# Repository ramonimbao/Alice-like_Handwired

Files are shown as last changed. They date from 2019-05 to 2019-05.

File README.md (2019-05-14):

# "fAuxLICE"

An 3D printable Alice-like mechanical keyboard

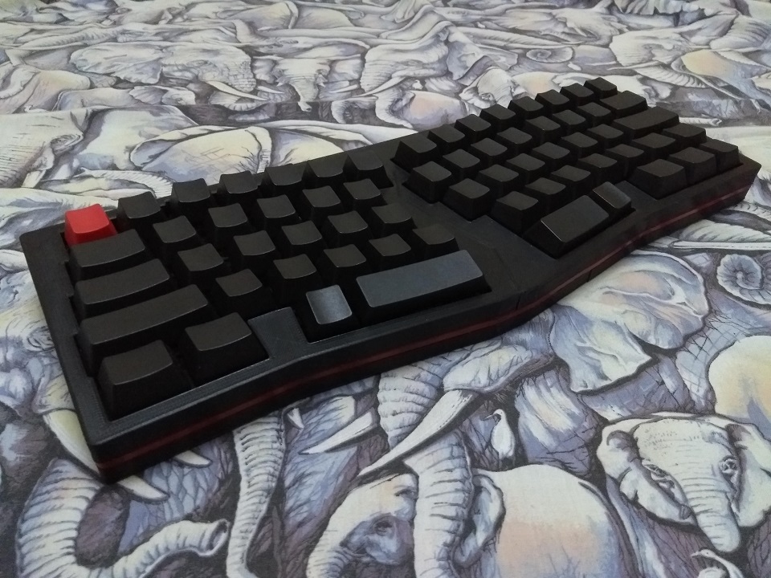
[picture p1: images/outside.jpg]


## Layout

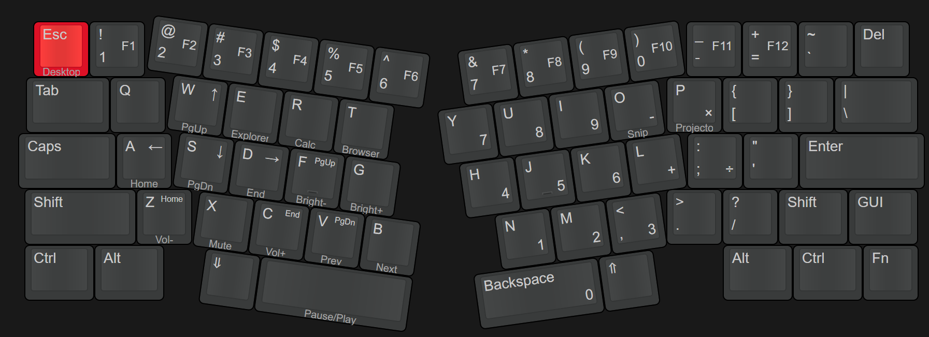
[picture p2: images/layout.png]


[Keyboard Layout Editor](http://www.keyboard-layout-editor.com/#/gists/7f17a55de07d88c1f975089b07f053b1)

## Components

### Required components

- 64× switches of your choice
- 4× plate-mounted Costar stabilizers
- 108-key keycap set
- 64× diodes
- Wires
- 14× M3×16 countersunk screws
- 2× M3×12 countersunk screws

### Optional components

- 1× M3×8 countersunk screw
- 1× M3×10 countersunk screw
- 1× M3×12 countersunk screw
- 1× M3×16 countersunk screw
- 1× M3×20 countersunk screw

The optional components are for reinforcing the top halves. They're not required. A proper glue up would be probably enough for the two halves.

## Wiring diagram

The keyboard is wired in a 5-row, 14-column configuration. Sorry for starting my row/column index at 1!

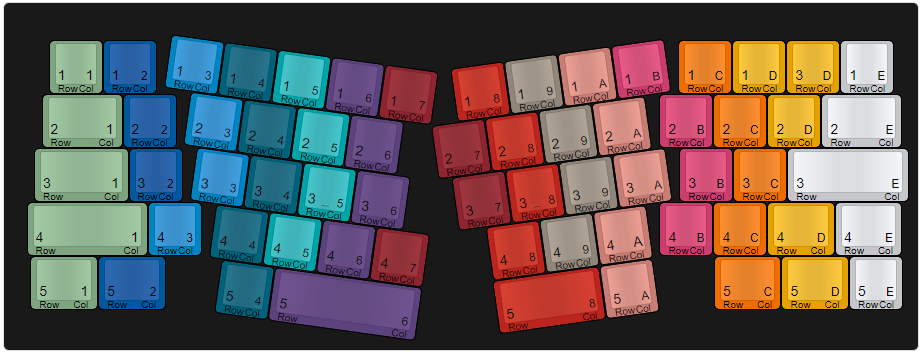
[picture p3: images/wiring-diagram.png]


## Build notes

The accent pieces have an extra 5mm sticking out. You should be able to cut them to the perfect length, and make the transitions between the two seamless. Glue the accent pieces to the bottom halves.

The halves do not lock into each other. I used a combination of glue and diode trimmings melted into the plastic.

I used a knife tip on my soldering iron and set the temperature to 250°C. Place the diode lead trimming on the plastic and melt it. I did this only on the inside surfaces so it wouldn't matter if it's ugly. I then supplemented it by melting loose filament into place.

## Firmware

The firmware included is for the STM32F103 ["Blue Pill"](https://wiki.stm32duino.com/index.php?title=Blue_Pill) board.

The STM32duino bootloader is not necessary. Simply flash the board using an ST-Link programmer.

## More info

More info can be found in [this blog post](https://ramonimbao.github.io/alice-like-keyboard/).

## License

This project is licensed under the MIT license. See the `LICENSE.md` for more details.

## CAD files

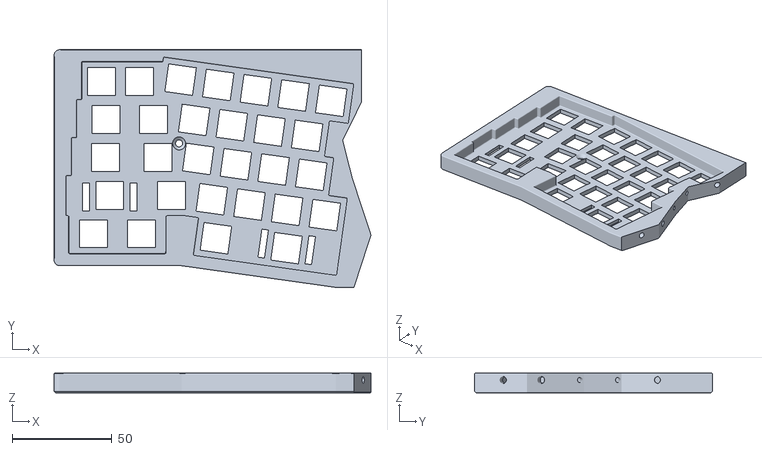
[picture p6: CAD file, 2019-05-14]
STL/fAuxLICE_Top_Left.stl
158.8 x 119.1 x 10.0

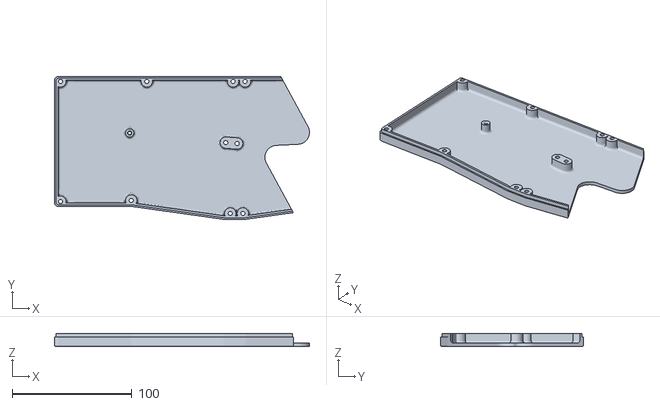
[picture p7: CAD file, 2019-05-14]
STL/fAuxLICE_Bottom_Left.stl
212.7 x 119.1 x 11.0

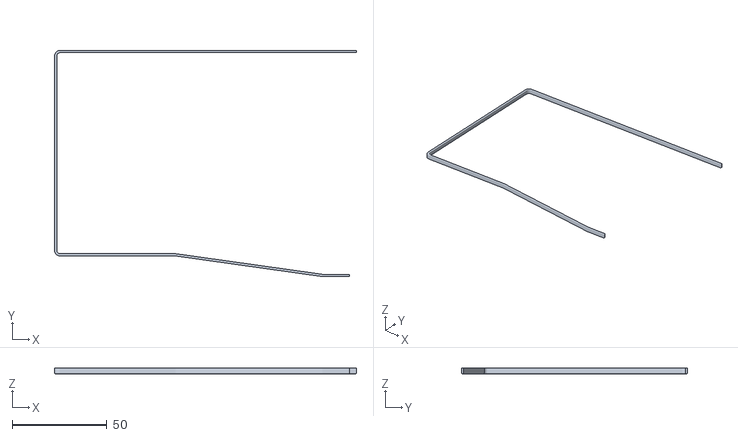
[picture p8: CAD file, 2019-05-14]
STL/fAuxLICE_Accent_Left.stl
159.0 x 119.1 x 3.00

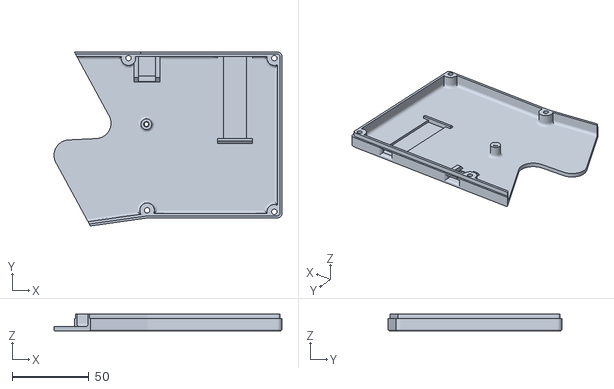
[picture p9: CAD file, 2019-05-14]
STL/fAuxLICE_Bottom_Right.stl
148.7 x 113.5 x 11.0

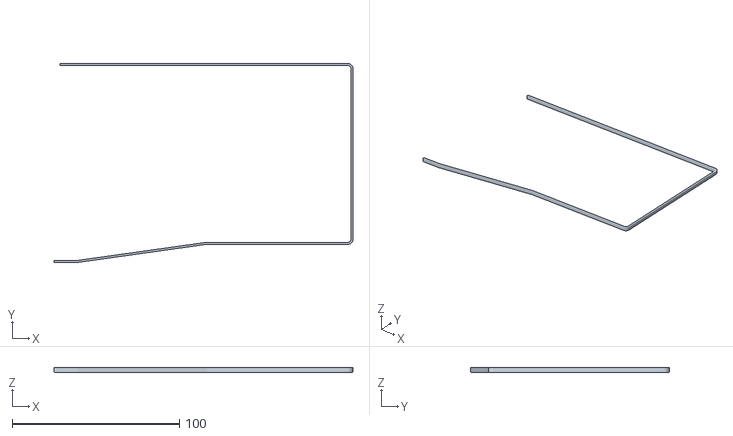
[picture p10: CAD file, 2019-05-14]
STL/fAuxLICE_Accent_Right.stl
179.0 x 119.1 x 3.00

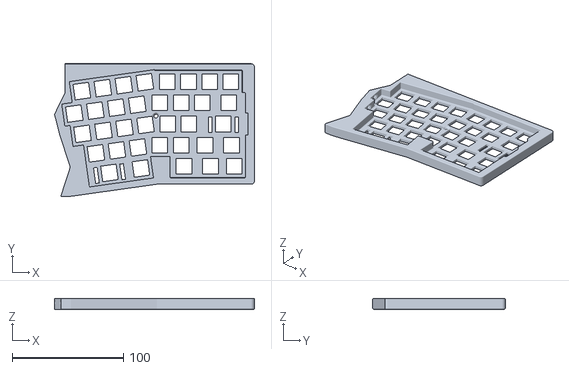
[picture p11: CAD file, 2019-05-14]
STL/fAuxLICE_Top_Right.stl
179.7 x 119.1 x 10.0

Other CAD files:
fusion360/fAuxLICE.f3d

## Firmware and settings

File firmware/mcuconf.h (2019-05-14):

/*
    ChibiOS - Copyright (C) 2006..2015 Giovanni Di Sirio

    Licensed under the Apache License, Version 2.0 (the "License");
    you may not use this file except in compliance with the License.
    You may obtain a copy of the License at

        http://www.apache.org/licenses/LICENSE-2.0

    Unless required by applicable law or agreed to in writing, software
    distributed under the License is distributed on an "AS IS" BASIS,
    WITHOUT WARRANTIES OR CONDITIONS OF ANY KIND, either express or implied.
    See the License for the specific language governing permissions and
    limitations under the License.
*/

#ifndef _MCUCONF_H_
#define _MCUCONF_H_

#define STM32F103_MCUCONF

/*
 * STM32F103 drivers configuration.
 * The following settings override the default settings present in
 * the various device driver implementation headers.
 * Note that the settings for each driver only have effect if the whole
 * driver is enabled in halconf.h.
 *
 * IRQ priorities:
 * 15...0       Lowest...Highest.
 *
 * DMA priorities:
 * 0...3        Lowest...Highest.
 */

/*
 * HAL driver system settings.
 */
#define STM32_NO_INIT                       FALSE
#define STM32_HSI_ENABLED                   TRUE
#define STM32_LSI_ENABLED                   FALSE
#define STM32_HSE_ENABLED                   TRUE
#define STM32_LSE_ENABLED                   FALSE
#define STM32_SW                            STM32_SW_PLL
#define STM32_PLLSRC                        STM32_PLLSRC_HSE
#define STM32_PLLXTPRE                      STM32_PLLXTPRE_DIV1
#define STM32_PLLMUL_VALUE                  9
#define STM32_HPRE                          STM32_HPRE_DIV1
#define STM32_PPRE1                         STM32_PPRE1_DIV2
#define STM32_PPRE2                         STM32_PPRE2_DIV2
#define STM32_ADCPRE                        STM32_ADCPRE_DIV4
#define STM32_USB_CLOCK_REQUIRED            TRUE
#define STM32_USBPRE                        STM32_USBPRE_DIV1P5
#define STM32_MCOSEL                        STM32_MCOSEL_NOCLOCK
#define STM32_RTCSEL                        STM32_RTCSEL_HSEDIV
#define STM32_PVD_ENABLE                    FALSE
#define STM32_PLS                           STM32_PLS_LEV0

/*
 * ADC driver system settings.
 */
#define STM32_ADC_USE_ADC1                  FALSE
#define STM32_ADC_ADC1_DMA_PRIORITY         2
#define STM32_ADC_ADC1_IRQ_PRIORITY         6

/*
 * CAN driver system settings.
 */
#define STM32_CAN_USE_CAN1                  FALSE
#define STM32_CAN_CAN1_IRQ_PRIORITY         11

/*
 * EXT driver system settings.
 */
#define STM32_EXT_EXTI0_IRQ_PRIORITY        6
#define STM32_EXT_EXTI1_IRQ_PRIORITY        6
#define STM32_EXT_EXTI2_IRQ_PRIORITY        6
#define STM32_EXT_EXTI3_IRQ_PRIORITY        6
#define STM32_EXT_EXTI4_IRQ_PRIORITY        6
#define STM32_EXT_EXTI5_9_IRQ_PRIORITY      6
#define STM32_EXT_EXTI10_15_IRQ_PRIORITY    6
#define STM32_EXT_EXTI16_IRQ_PRIORITY       6
#define STM32_EXT_EXTI17_IRQ_PRIORITY       6
#define STM32_EXT_EXTI18_IRQ_PRIORITY       6
#define STM32_EXT_EXTI19_IRQ_PRIORITY       6

/*
 * GPT driver system settings.
 */
#define STM32_GPT_USE_TIM1                  FALSE
#define STM32_GPT_USE_TIM2                  FALSE
#define STM32_GPT_USE_TIM3                  FALSE
#define STM32_GPT_USE_TIM4                  FALSE
#define STM32_GPT_USE_TIM5                  FALSE
#define STM32_GPT_USE_TIM8                  FALSE
#define STM32_GPT_TIM1_IRQ_PRIORITY         7
#define STM32_GPT_TIM2_IRQ_PRIORITY         7
#define STM32_GPT_TIM3_IRQ_PRIORITY         7
#define STM32_GPT_TIM4_IRQ_PRIORITY         7
#define STM32_GPT_TIM5_IRQ_PRIORITY         7
#define STM32_GPT_TIM8_IRQ_PRIORITY         7

/*
 * I2C driver system settings.
 */
#define STM32_I2C_USE_I2C1                  FALSE
#define STM32_I2C_USE_I2C2                  FALSE
#define STM32_I2C_BUSY_TIMEOUT              50
#define STM32_I2C_I2C1_IRQ_PRIORITY         5
#define STM32_I2C_I2C2_IRQ_PRIORITY         5
#define STM32_I2C_I2C1_DMA_PRIORITY         3
#define STM32_I2C_I2C2_DMA_PRIORITY         3
#define STM32_I2C_DMA_ERROR_HOOK(i2cp)      osalSysHalt("DMA failure")

/*
 * ICU driver system settings.
 */
#define STM32_ICU_USE_TIM1                  FALSE
#define STM32_ICU_USE_TIM2                  FALSE
#define STM32_ICU_USE_TIM3                  FALSE
#define STM32_ICU_USE_TIM4                  FALSE
#define STM32_ICU_USE_TIM5                  FALSE
#define STM32_ICU_USE_TIM8                  FALSE
#define STM32_ICU_TIM1_IRQ_PRIORITY         7
#define STM32_ICU_TIM2_IRQ_PRIORITY         7
#define STM32_ICU_TIM3_IRQ_PRIORITY         7
#define STM32_ICU_TIM4_IRQ_PRIORITY         7
#define STM32_ICU_TIM5_IRQ_PRIORITY         7
#define STM32_ICU_TIM8_IRQ_PRIORITY         7

/*
 * PWM driver system settings.
 */
#define STM32_PWM_USE_ADVANCED              FALSE
#define STM32_PWM_USE_TIM1                  TRUE
#define STM32_PWM_USE_TIM2                  FALSE
#define STM32_PWM_USE_TIM3                  FALSE
#define STM32_PWM_USE_TIM4                  FALSE
#define STM32_PWM_USE_TIM5                  FALSE
#define STM32_PWM_USE_TIM8                  FALSE
#define STM32_PWM_TIM1_IRQ_PRIORITY         7
#define STM32_PWM_TIM2_IRQ_PRIORITY         7
#define STM32_PWM_TIM3_IRQ_PRIORITY         7
#define STM32_PWM_TIM4_IRQ_PRIORITY         7
#define STM32_PWM_TIM5_IRQ_PRIORITY         7
#define STM32_PWM_TIM8_IRQ_PRIORITY         7

/*
 * RTC driver system settings.
 */
#define STM32_RTC_IRQ_PRIORITY              15

/*
 * SERIAL driver system settings.
 */
#define STM32_SERIAL_USE_USART1             FALSE
#define STM32_SERIAL_USE_USART2             FALSE
#define STM32_SERIAL_USE_USART3             FALSE
#define STM32_SERIAL_USE_UART4              FALSE
#define STM32_SERIAL_USE_UART5              FALSE
#define STM32_SERIAL_USART1_PRIORITY        12
#define STM32_SERIAL_USART2_PRIORITY        12
#define STM32_SERIAL_USART3_PRIORITY        12
#define STM32_SERIAL_UART4_PRIORITY         12
#define STM32_SERIAL_UART5_PRIORITY         12

/*
 * SPI driver system settings.
 */
#define STM32_SPI_USE_SPI1                  FALSE
#define STM32_SPI_USE_SPI2                  FALSE
#define STM32_SPI_USE_SPI3                  FALSE
#define STM32_SPI_SPI1_DMA_PRIORITY         1
#define STM32_SPI_SPI2_DMA_PRIORITY         1
#define STM32_SPI_SPI3_DMA_PRIORITY         1
#define STM32_SPI_SPI1_IRQ_PRIORITY         10
#define STM32_SPI_SPI2_IRQ_PRIORITY         10
#define STM32_SPI_SPI3_IRQ_PRIORITY         10
#define STM32_SPI_DMA_ERROR_HOOK(spip)      osalSysHalt("DMA failure")

/*
 * ST driver system settings.
 */
#define STM32_ST_IRQ_PRIORITY               8
#define STM32_ST_USE_TIMER                  2
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

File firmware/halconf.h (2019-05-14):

/*
    ChibiOS - Copyright (C) 2006..2015 Giovanni Di Sirio

    Licensed under the Apache License, Version 2.0 (the "License");
    you may not use this file except in compliance with the License.
    You may obtain a copy of the License at

        http://www.apache.org/licenses/LICENSE-2.0

    Unless required by applicable law or agreed to in writing, software
    distributed under the License is distributed on an "AS IS" BASIS,
    WITHOUT WARRANTIES OR CONDITIONS OF ANY KIND, either express or implied.
    See the License for the specific language governing permissions and
    limitations under the License.
*/

/**
 * @file    templates/halconf.h
 * @brief   HAL configuration header.
 * @details HAL configuration file, this file allows to enable or disable the
 *          various device drivers from your application. You may also use
 *          this file in order to override the device drivers default settings.
 *
 * @addtogroup HAL_CONF
 * @{
 */

#ifndef _HALCONF_H_
#define _HALCONF_H_

#include "mcuconf.h"

/**
 * @brief   Enables the PAL subsystem.
 */
#if !defined(HAL_USE_PAL) || defined(__DOXYGEN__)
#define HAL_USE_PAL                 TRUE
#endif

/**
 * @brief   Enables the ADC subsystem.
 */
#if !defined(HAL_USE_ADC) || defined(__DOXYGEN__)
#define HAL_USE_ADC                 FALSE
#endif

/**
 * @brief   Enables the CAN subsystem.
 */
#if !defined(HAL_USE_CAN) || defined(__DOXYGEN__)
#define HAL_USE_CAN                 FALSE
#endif

/**
 * @brief   Enables the DAC subsystem.
 */
#if !defined(HAL_USE_DAC) || defined(__DOXYGEN__)
#define HAL_USE_DAC                 FALSE
#endif

/**
 * @brief   Enables the EXT subsystem.
 */
#if !defined(HAL_USE_EXT) || defined(__DOXYGEN__)
#define HAL_USE_EXT                 FALSE
#endif

/**
 * @brief   Enables the GPT subsystem.
 */
#if !defined(HAL_USE_GPT) || defined(__DOXYGEN__)
#define HAL_USE_GPT                 FALSE
#endif

/**
 * @brief   Enables the I2C subsystem.
 */
#if !defined(HAL_USE_I2C) || defined(__DOXYGEN__)
#define HAL_USE_I2C                 FALSE
#endif

/**
 * @brief   Enables the I2S subsystem.
 */
#if !defined(HAL_USE_I2S) || defined(__DOXYGEN__)
#define HAL_USE_I2S                 FALSE
#endif

/**
 * @brief   Enables the ICU subsystem.
 */
#if !defined(HAL_USE_ICU) || defined(__DOXYGEN__)
#define HAL_USE_ICU                 FALSE
#endif

/**
 * @brief   Enables the MAC subsystem.
 */
#if !defined(HAL_USE_MAC) || defined(__DOXYGEN__)
#define HAL_USE_MAC                 FALSE
#endif

/**
 * @brief   Enables the MMC_SPI subsystem.
 */
#if !defined(HAL_USE_MMC_SPI) || defined(__DOXYGEN__)
#define HAL_USE_MMC_SPI             FALSE
#endif

/**
 * @brief   Enables the PWM subsystem.
 */
#if !defined(HAL_USE_PWM) || defined(__DOXYGEN__)
#define HAL_USE_PWM                 FALSE
#endif

/**
 * @brief   Enables the RTC subsystem.
 */
#if !defined(HAL_USE_RTC) || defined(__DOXYGEN__)
#define HAL_USE_RTC                 FALSE
#endif

/**
 * @brief   Enables the SDC subsystem.
 */
#if !defined(HAL_USE_SDC) || defined(__DOXYGEN__)
#define HAL_USE_SDC                 FALSE
#endif

/**
 * @brief   Enables the SERIAL subsystem.
 */
#if !defined(HAL_USE_SERIAL) || defined(__DOXYGEN__)
#define HAL_USE_SERIAL              FALSE
#endif

/**
 * @brief   Enables the SERIAL over USB subsystem.
 */
#if !defined(HAL_USE_SERIAL_USB) || defined(__DOXYGEN__)
#define HAL_USE_SERIAL_USB          FALSE
#endif

/**
 * @brief   Enables the SPI subsystem.
 */
#if !defined(HAL_USE_SPI) || defined(__DOXYGEN__)
#define HAL_USE_SPI                 FALSE
#endif

/**
 * @brief   Enables the UART subsystem.
 */
#if !defined(HAL_USE_UART) || defined(__DOXYGEN__)
#define HAL_USE_UART                FALSE
#endif

/**
 * @brief   Enables the USB subsystem.
 */
#if !defined(HAL_USE_USB) || defined(__DOXYGEN__)
#define HAL_USE_USB                 TRUE
#endif

/**
 * @brief   Enables the WDG subsystem.
 */
#if !defined(HAL_USE_WDG) || defined(__DOXYGEN__)
#define HAL_USE_WDG                 FALSE
#endif

/*===========================================================================*/
/* ADC driver related settings.                                              */
/*===========================================================================*/

/**
 * @brief   Enables synchronous APIs.
 * @note    Disabling this option saves both code and data space.
 */
#if !defined(ADC_USE_WAIT) || defined(__DOXYGEN__)
#define ADC_USE_WAIT                TRUE
#endif

/**
 * @brief   Enables the @p adcAcquireBus() and @p adcReleaseBus() APIs.
 * @note    Disabling this option saves both code and data space.
 */
#if !defined(ADC_USE_MUTUAL_EXCLUSION) || defined(__DOXYGEN__)
#define ADC_USE_MUTUAL_EXCLUSION    TRUE
#endif

/*===========================================================================*/
/* CAN driver related settings.                                              */
/*===========================================================================*/

/**
 * @brief   Sleep mode related APIs inclusion switch.
 */
#if !defined(CAN_USE_SLEEP_MODE) || defined(__DOXYGEN__)
#define CAN_USE_SLEEP_MODE          TRUE
#endif

/*===========================================================================*/
/* I2C driver related settings.                                              */
/*===========================================================================*/

/**
 * @brief   Enables the mutual exclusion APIs on the I2C bus.
 */
#if !defined(I2C_USE_MUTUAL_EXCLUSION) || defined(__DOXYGEN__)
#define I2C_USE_MUTUAL_EXCLUSION    TRUE
#endif

/*===========================================================================*/
/* MAC driver related settings.                                              */
/*===========================================================================*/

/**
 * @brief   Enables an event sources for incoming packets.
 */
#if !defined(MAC_USE_ZERO_COPY) || defined(__DOXYGEN__)
#define MAC_USE_ZERO_COPY           FALSE
#endif

/**
 * @brief   Enables an event sources for incoming packets.
 */
#if !defined(MAC_USE_EVENTS) || defined(__DOXYGEN__)
#define MAC_USE_EVENTS              TRUE
#endif

/*===========================================================================*/
/* MMC_SPI driver related settings.                                          */
/*===========================================================================*/

/**
 * @brief   Delays insertions.
 * @details If enabled this options inserts delays into the MMC waiting
 *          routines releasing some extra CPU time for the threads with
 *          lower priority, this may slow down the driver a bit however.
 *          This option is recommended also if the SPI driver does not
 *          use a DMA channel and heavily loads the CPU.
 */
#if !defined(MMC_NICE_WAITING) || defined(__DOXYGEN__)
#define MMC_NICE_WAITING            TRUE
#endif
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

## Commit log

2019-05-14 Add firmware and wiring diagram
2019-05-14 Add images and Fusion 360 source file
    [fAuxLICE.f3d]
